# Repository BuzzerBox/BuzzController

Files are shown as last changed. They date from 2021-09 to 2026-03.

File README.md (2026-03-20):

# BuzzController

Firmware and hardware designs for the BuzzerBox — a 10-button quiz buzzer controller. A Raspberry Pi CM4 acts as the host, communicating with an ATmega328P co-processor over serial. The ATmega handles button detection, locks the active buzzer, and drives a 7-segment display.

---

## Features

- **10 buzzers** with individual LED feedback, interrupt-driven detection
- **7-segment display** showing the active buzzer number and RPi connection status
- **Serial communication** with a Raspberry Pi at 115200 baud, including heartbeat monitoring
- **Soft release** — RPi can remotely unlock the selected buzzer
- **Watchdog timer** for automatic recovery from firmware hangs
- **I2C I/O expanders** (MCP23017) to drive LEDs and display

---

## Repository Structure

```
BuzzController/
├── cad/
│   └── BuzzerBox/
│       ├── controller.brd/.sch    # Main ATmega328P controller board
│       ├── xlrpcb.brd/.sch        # XLR connector board (V3)
│       ├── devkeys.brd/.sch       # Development key PCB
│       ├── ttl_adapter.brd/.sch   # TTL adapter for devkit
│       └── eagle.epf              # EAGLE CAD project file
│   └── BuzzerBoxPanel.f3d         # Fusion 360 enclosure design
└── code/
    ├── platformio.ini             # Build configuration
    └── src/
        ├── BuzzerBox.cpp          # Main firmware logic
        ├── i2c_communication.*    # MCP23017 I/O expander driver
        ├── rpi_communication.*    # Serial protocol with Raspberry Pi
        ├── 7segment.*             # 7-segment display driver
        └── portConfig.hpp         # Pin/port and I2C address configuration
```

---

## Hardware

| Component | Details |
|---|---|
| Host | Raspberry Pi CM4 (mounted directly on PCB) |
| Microcontroller | ATmega328P |
| I/O Expanders | 2× MCP23017 (I2C addresses `0x20`, `0x21`) |
| Display | 7-segment LED (common cathode, via expander) |
| Buttons | 10 buzzers across MCU ports B, C, D + 1 release button |
| CM4 ↔ MCU | Serial UART (115200 baud) |
| Programming | STK500v2 via USB |

PCB designs are in [EAGLE](https://www.autodesk.com/products/eagle/overview) format. The enclosure panel is a [Fusion 360](https://www.autodesk.com/products/fusion-360/overview) file.

---

## Serial Protocol

Communication between the ATmega328P and the Raspberry Pi uses 3-byte UART messages at **115200 baud**:

```
[Command Byte] [Data Byte] [0xFF]
```

### Commands (RPi → Controller)

| Command | Value | Description |
|---|---|---|
| `EMPTY` | `0x00` | No operation |
| `SOFT_RELEASE` | `0x01` | Unlock the active buzzer |
| `SET_BUZZER` | `0x02` | Lock a specific buzzer (data = buzzer ID 0–9) |

### Events (Controller → RPi)

| Event | Byte | Description |
|---|---|---|
| Button pressed | `'0'`–`'9'` (ASCII) | Buzzer ID of the pressed button |
| Buzzer unlocked | `'q'` | Acknowledges an unlock |

A heartbeat is expected from the RPi every **6 seconds**. If no heartbeat is received within this window, the controller transitions to a disconnected state and reflects this on the display's decimal point.

---

## Building and Flashing

The firmware uses [PlatformIO](https://platformio.org/).

```bash
# Install PlatformIO CLI or use the VSCode extension

# Build
pio run

# Upload
pio run --target upload
```

Upload uses STK500v2 at 19200 baud over USB.

---

## Development

The `devkeys` PCB and `ttl_adapter` PCB are development accessories for testing the firmware without the full buzzer assembly.

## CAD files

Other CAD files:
cad/BuzzerBoxPanel.f3d

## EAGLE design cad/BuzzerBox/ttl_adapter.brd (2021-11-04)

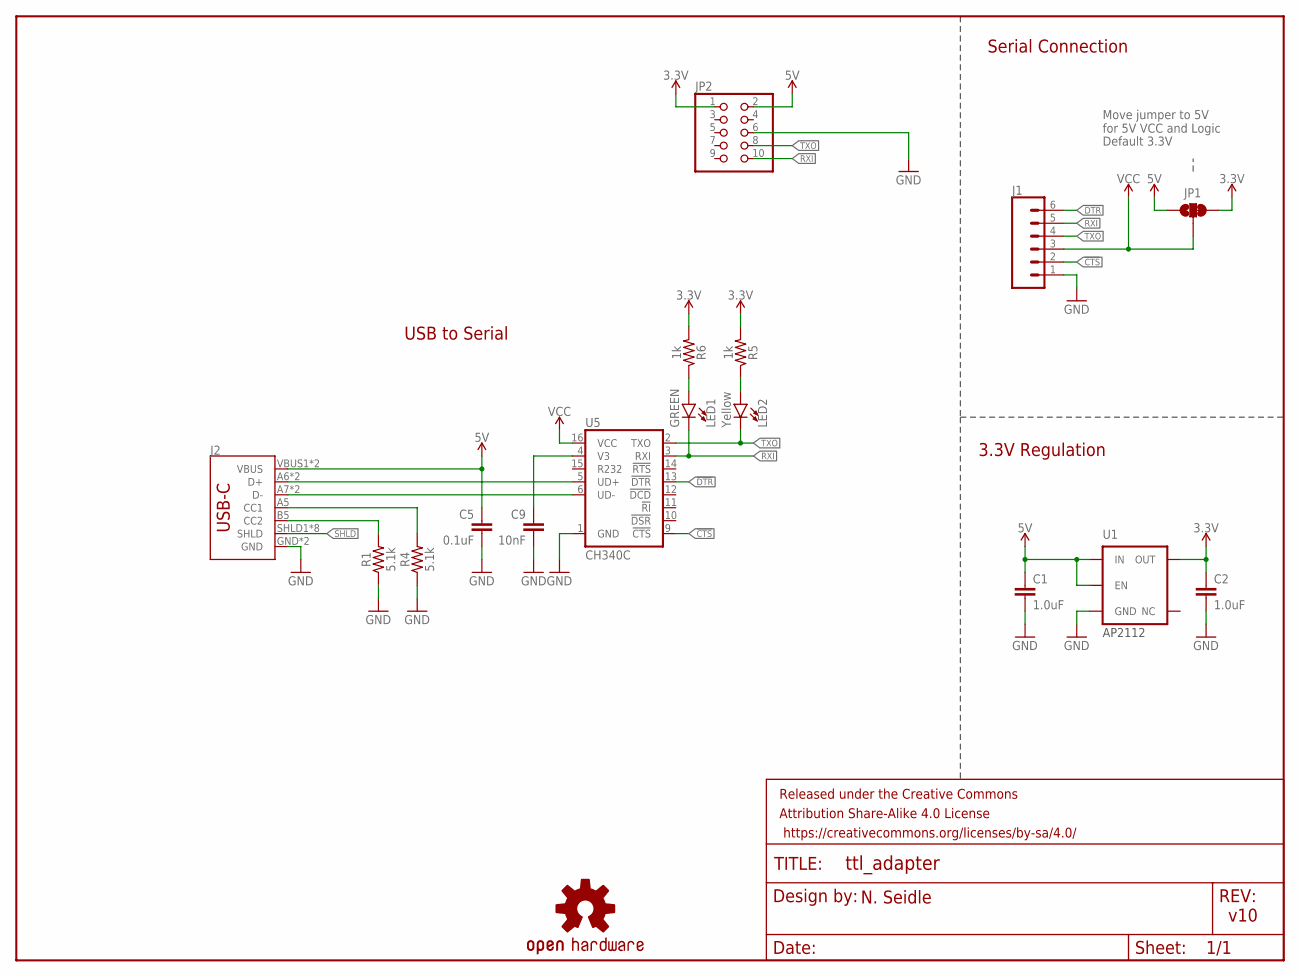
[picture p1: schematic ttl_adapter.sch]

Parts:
C1, C2: 1.0uF; 0603
C5: 0.1uF; 0603
C9: 10nF; 0603
FRAME1: FRAME-LETTER; CREATIVE_COMMONS
J1: CONN_06SMD-FEMALE-V2; 1X06-SMD-FEMALE
J2: USB_C16PIN; USB-C-16P
JP1: JUMPER-SMT_3_1-NC_TRACE_SILK; SMT-JUMPER_3_1-NC_TRACE_SILK
JP2: PINHD-2X5; 2X05
LED1: GREEN; LED-0603
LED2: Yellow; LED-0603
LOGO1: OSHW-LOGOS; OSHW-LOGO-S
R1, R4: 5.1k; 0603
R5, R6: 1k; 0603
U1: 3.3V; SOT23-5
U5: CH340C; SO016

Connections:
3.3V: C2.1, JP1.3, JP2.1, R5.2, R6.2, U1.5 (OUT)
5V: C1.1, C5.1, J2.VBUS1 (VBUS), J2.VBUS2 (VBUS), JP1.1, JP2.2, U1.1 (IN), U1.3 (EN)
!CTS: J1.2, U5.9 (!CTS)
!DTR: J1.6, U5.13 (!DTR)
CC1: J2.A5 (CC1), R4.2
CC2: J2.B5 (CC2), R1.2
D+: J2.A6 (D+), J2.B6 (D+), U5.5 (UD+)
D-: J2.A7 (D-), J2.B7 (D-), U5.6 (UD-)
GND: C1.2, C2.2, C5.2, C9.2, J1.1, J2.GND, J2.GND2 (GND), JP2.6, R1.1, R4.1, U1.2 (GND), U5.1 (GND)
unnamed: C9.1, U5.4 (V3)
unnamed: LED1.A, R6.1
unnamed: LED2.A, R5.1
RXI: J1.5, JP2.10, LED1.C, U5.3 (RXI)
SHLD: J2.SHLD1 (SHLD), J2.SHLD2 (SHLD), J2.SHLD3 (SHLD), J2.SHLD4 (SHLD), J2.SHLD5 (SHLD), J2.SHLD6 (SHLD), J2.SHLD7 (SHLD), J2.SHLD8 (SHLD)
TXO: J1.4, JP2.8, LED2.C, U5.2 (TXO)
VCC: J1.3, JP1.2, U5.16 (VCC)

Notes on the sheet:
Default 3.3V
v10
USB to Serial
3.3V Regulation
N. Seidle
Move jumper to 5V for 5V VCC and Logic
Serial Connection
AP2112

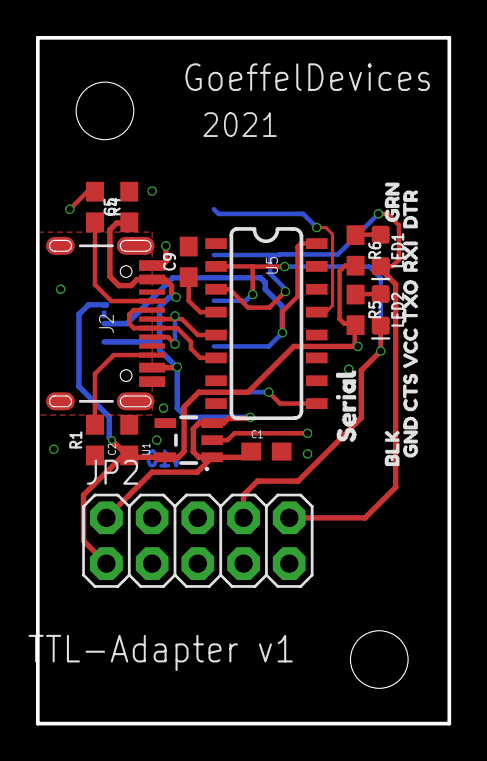
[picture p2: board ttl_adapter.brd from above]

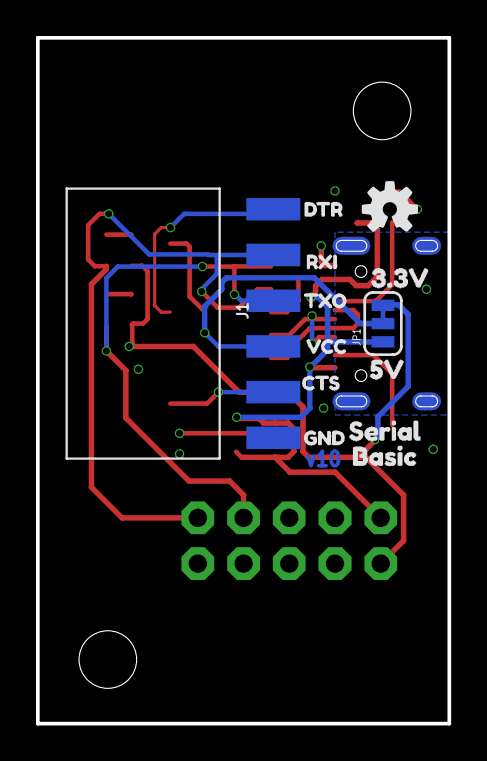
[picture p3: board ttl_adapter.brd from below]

Board: 2 copper layers, 22.9 x 38.1 mm, 39 parts (13 on the bottom side), 16 nets.

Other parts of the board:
U$1, U$14: CTS1
U$2: 3#3V8
U$3: 5V9
U$4, U$9: SERIAL0
U$5, U$12: TXO0
U$6, U$13: VCC2
U$8, U$18: DTR0
U$10, U$21: RXI1
U$11: BASIC1
U$15, U$19: GND5
U$16, U$22: M3-HOLE
U$17: BLK6
U$20: GRN7

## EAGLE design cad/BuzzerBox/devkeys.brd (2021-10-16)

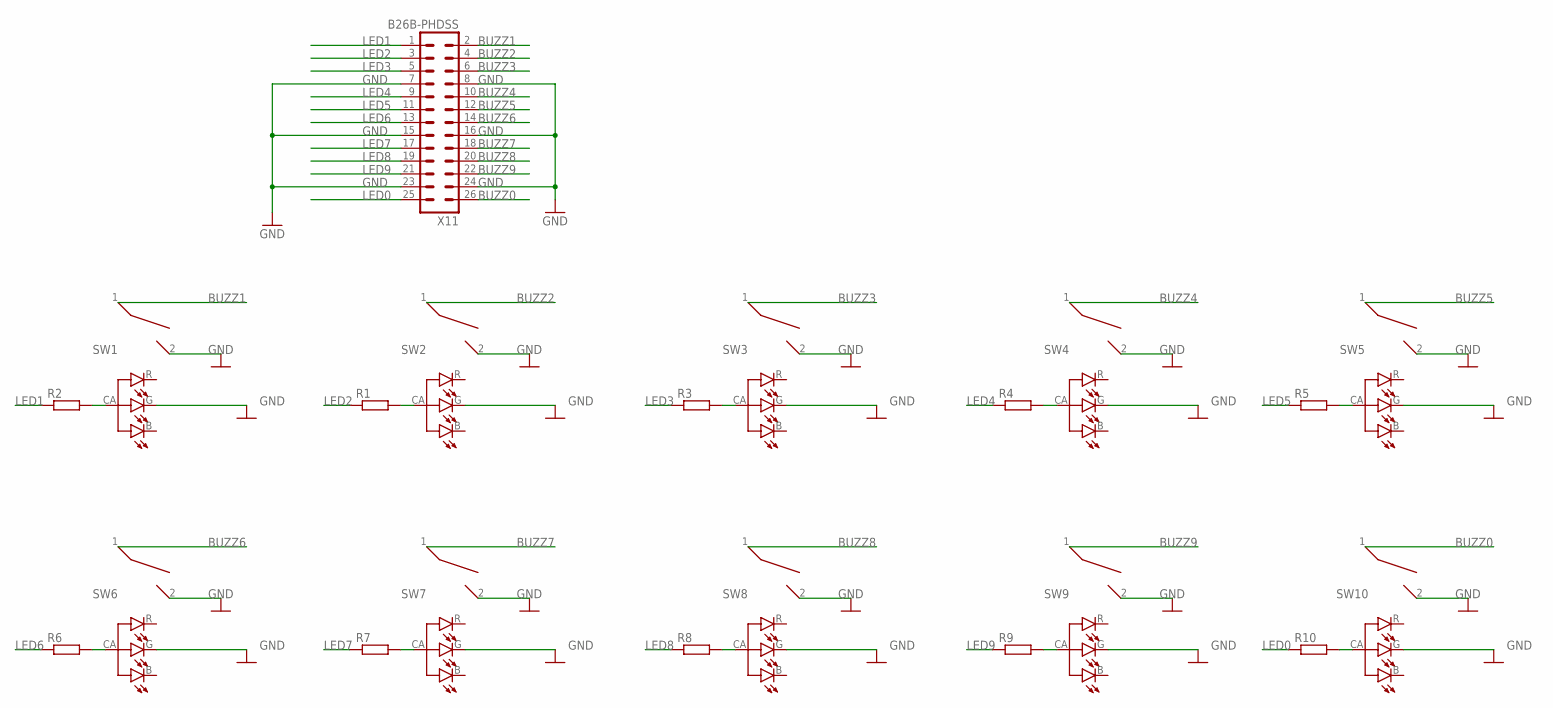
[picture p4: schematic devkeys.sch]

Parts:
R1, R2, R3, R4, R5, R6, R7, R8, R9, R10: R-EU_R0805; R0805
SW1, SW2, SW3, SW4, SW5, SW6, SW7, SW8, SW9, SW10: ZEALIOS; ZEALIOS-PCB_1U
X11: B26B-PHDSS

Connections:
BUZZ0: SW10.1, X11.26
BUZZ1: SW1.1, X11.2
BUZZ2: SW2.1, X11.4
BUZZ3: SW3.1, X11.6
BUZZ4: SW4.1, X11.10
BUZZ5: SW5.1, X11.12
BUZZ6: SW6.1, X11.14
BUZZ7: SW7.1, X11.18
BUZZ8: SW8.1, X11.20
BUZZ9: SW9.1, X11.22
GND: SW1.2, SW1.G (G-CAT), SW2.2, SW2.G (G-CAT), SW3.2, SW3.G (G-CAT), SW4.2, SW4.G (G-CAT), SW5.2, SW5.G (G-CAT), SW6.2, SW6.G (G-CAT), SW7.2, SW7.G (G-CAT), SW8.2, SW8.G (G-CAT), SW9.2, SW9.G (G-CAT), SW10.2, SW10.G (G-CAT), X11.7, X11.8, X11.15, X11.16, X11.23, X11.24
LED0: R10.1, X11.25
LED1: R2.1, X11.1
LED2: R1.1, X11.3
LED3: R3.1, X11.5
LED4: R4.1, X11.9
LED5: R5.1, X11.11
LED6: R6.1, X11.13
LED7: R7.1, X11.17
LED8: R8.1, X11.19
LED9: R9.1, X11.21
unnamed: R1.2, SW2.CA (COMMON-ANODE)
unnamed: R2.2, SW1.CA (COMMON-ANODE)
unnamed: R3.2, SW3.CA (COMMON-ANODE)
unnamed: R4.2, SW4.CA (COMMON-ANODE)
unnamed: R5.2, SW5.CA (COMMON-ANODE)
unnamed: R6.2, SW6.CA (COMMON-ANODE)
unnamed: R7.2, SW7.CA (COMMON-ANODE)
unnamed: R8.2, SW8.CA (COMMON-ANODE)
unnamed: R9.2, SW9.CA (COMMON-ANODE)
unnamed: R10.2, SW10.CA (COMMON-ANODE)

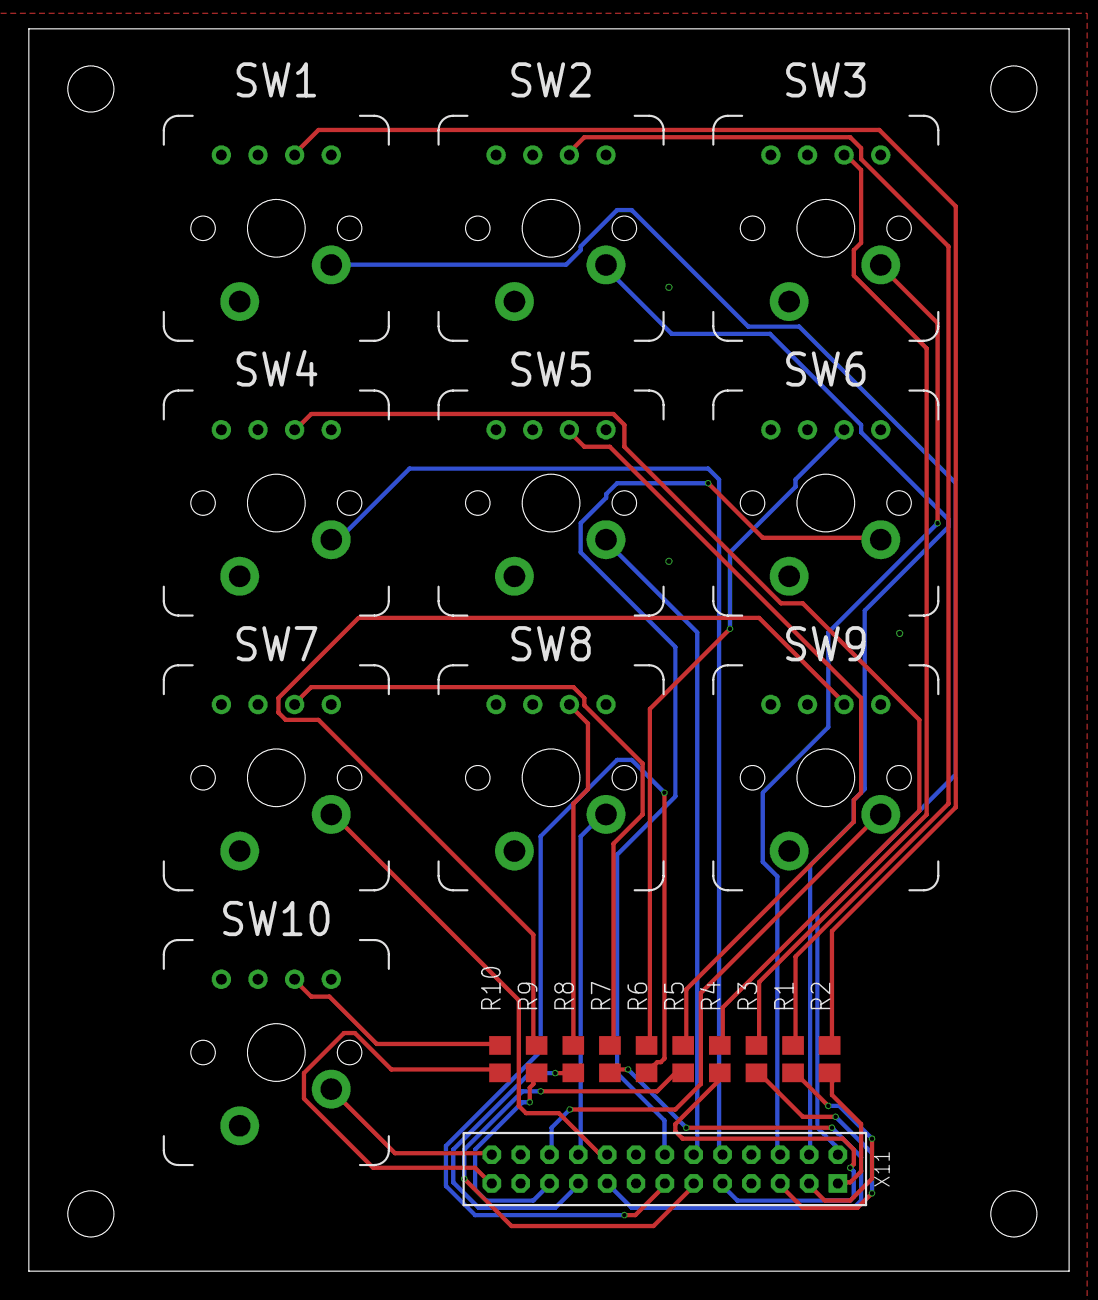
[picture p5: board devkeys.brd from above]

Board: 2 copper layers, 72.1 x 86.1 mm, 25 parts (0 on the bottom side), 31 nets.

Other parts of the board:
U$1, U$2, U$3, U$4: M3-HOLE

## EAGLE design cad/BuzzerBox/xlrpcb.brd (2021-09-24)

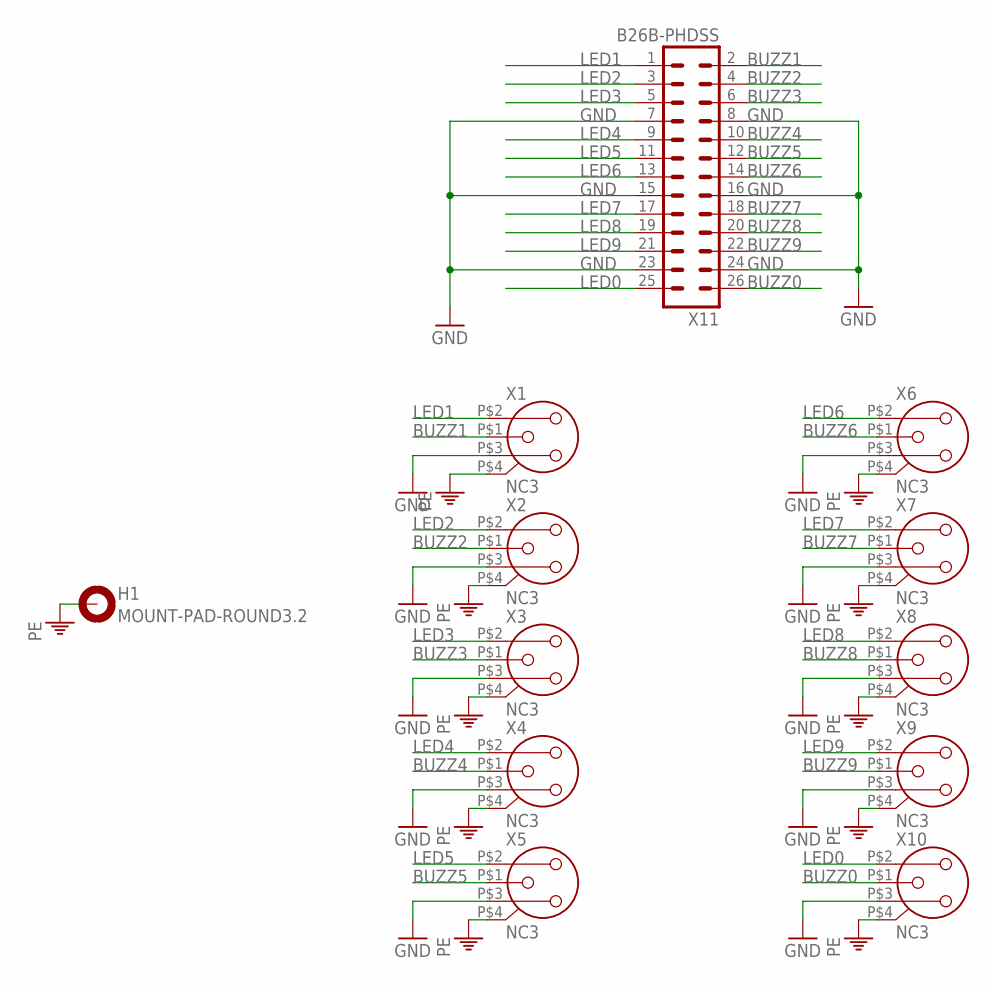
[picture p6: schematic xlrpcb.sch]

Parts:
H1: MOUNT-PAD-ROUND3.2; 3,2-PAD
X1, X2, X3, X4, X5, X6, X7, X8, X9, X10: NC3; NC3FD-X
X11: B26B-PHDSS

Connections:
BUZZ0: X10.P$1 (3), X11.26
BUZZ1: X1.P$1 (3), X11.2
BUZZ2: X2.P$1 (3), X11.4
BUZZ3: X3.P$1 (3), X11.6
BUZZ4: X4.P$1 (3), X11.10
BUZZ5: X5.P$1 (3), X11.12
BUZZ6: X6.P$1 (3), X11.14
BUZZ7: X7.P$1 (3), X11.18
BUZZ8: X8.P$1 (3), X11.20
BUZZ9: X9.P$1 (3), X11.22
GND: X1.P$3 (2), X2.P$3 (2), X3.P$3 (2), X4.P$3 (2), X5.P$3 (2), X6.P$3 (2), X7.P$3 (2), X8.P$3 (2), X9.P$3 (2), X10.P$3 (2), X11.7, X11.8, X11.15, X11.16, X11.23, X11.24
LED0: X10.P$2 (1), X11.25
LED1: X1.P$2 (1), X11.1
LED2: X2.P$2 (1), X11.3
LED3: X3.P$2 (1), X11.5
LED4: X4.P$2 (1), X11.9
LED5: X5.P$2 (1), X11.11
LED6: X6.P$2 (1), X11.13
LED7: X7.P$2 (1), X11.17
LED8: X8.P$2 (1), X11.19
LED9: X9.P$2 (1), X11.21
PE: H1.B3,2, X1.P$4 (G), X2.P$4 (G), X3.P$4 (G), X4.P$4 (G), X5.P$4 (G), X6.P$4 (G), X7.P$4 (G), X8.P$4 (G), X9.P$4 (G), X10.P$4 (G)

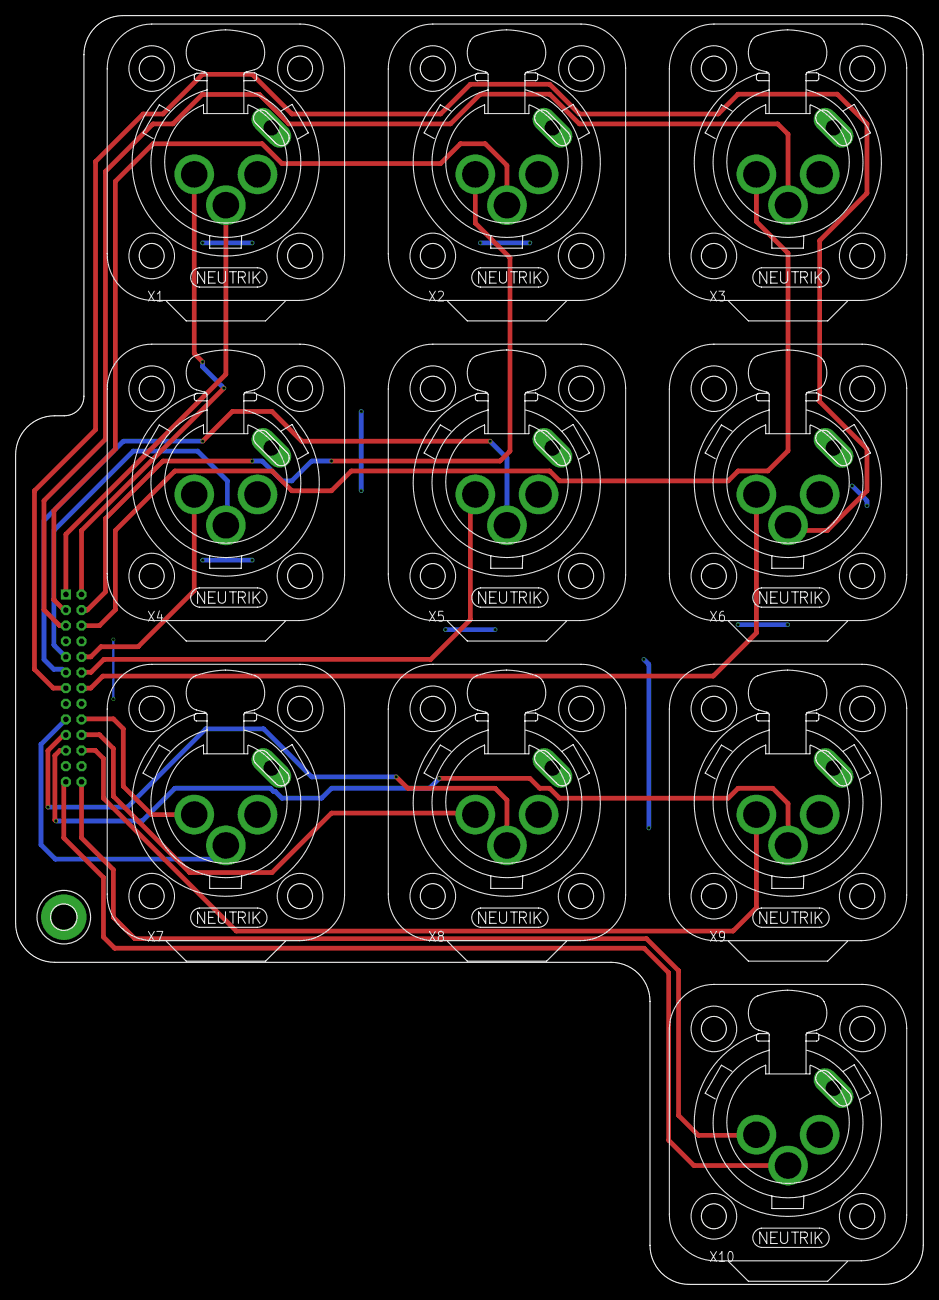
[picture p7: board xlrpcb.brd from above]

Board: 2 copper layers, 116.2 x 162.5 mm, 12 parts (1 on the bottom side), 22 nets.

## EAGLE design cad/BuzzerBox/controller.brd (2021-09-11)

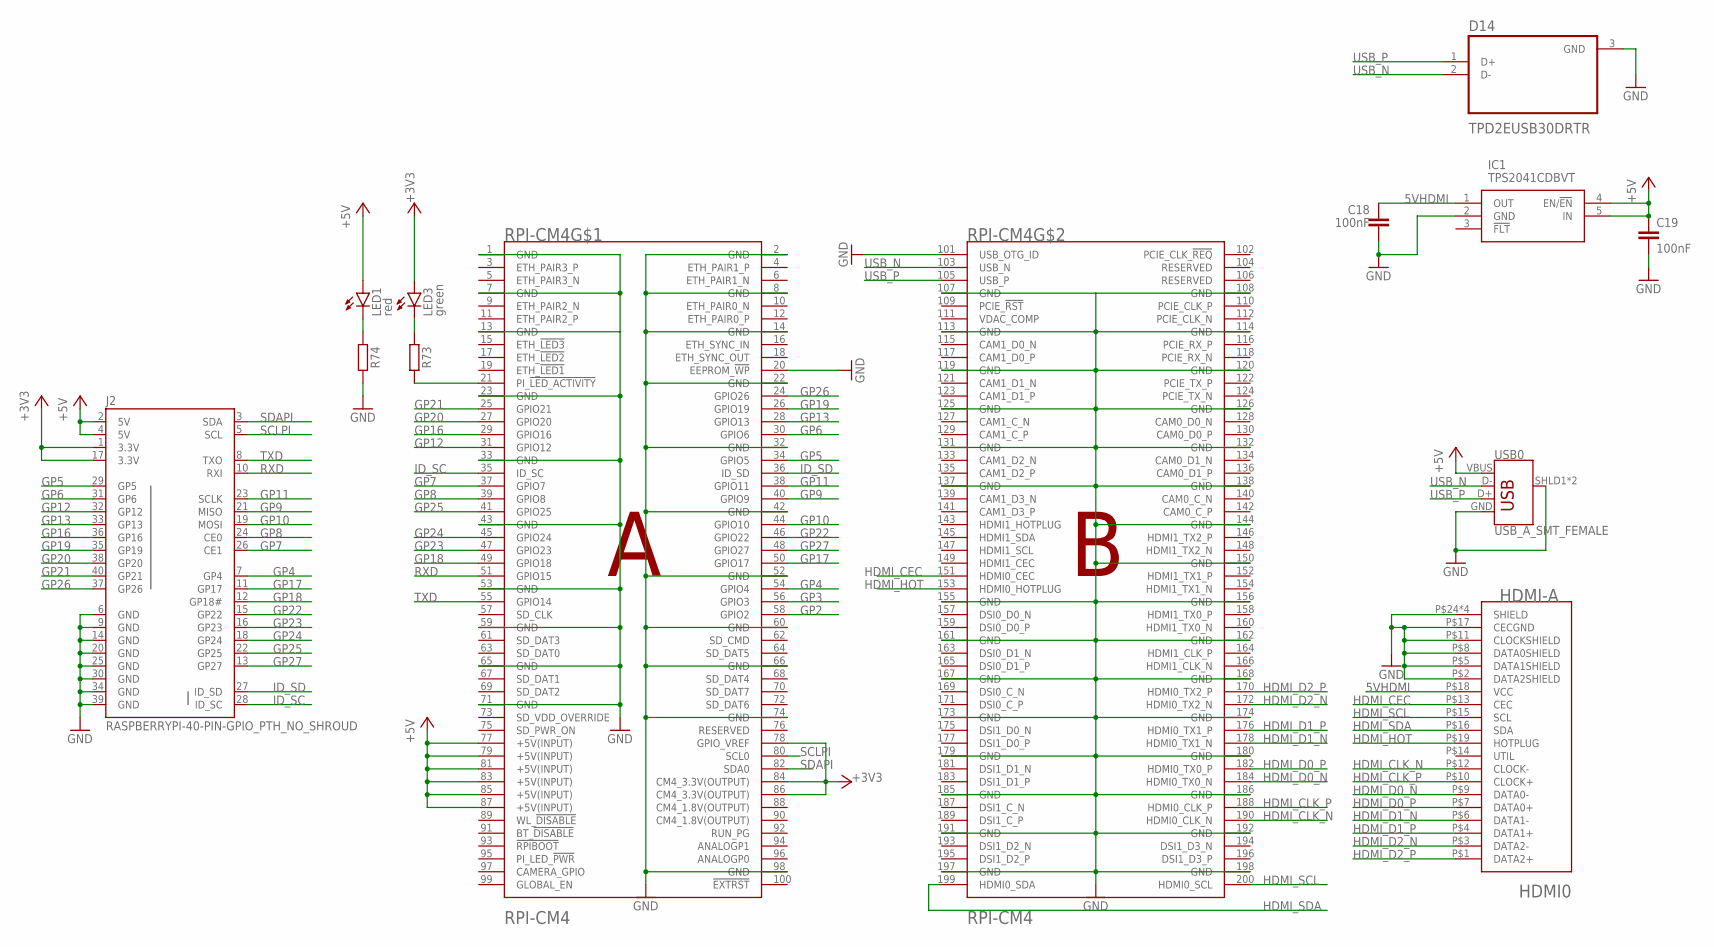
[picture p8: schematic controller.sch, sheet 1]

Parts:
C18, C19: 100nF; C0805
D14: TPD2EUSB30DRTR; SOTFL35P100X50-3N
HDMI0: HDMI-A; HDMI_A
IC1: TPS2041CDBVT; SOT95P280X145-5N
J2: RASPBERRYPI-40-PIN-GPIO_PTH_NO_SHROUD; 2X20
LED1: red; CHIP-LED0805
LED3: green; CHIP-LED0805
R73, R74: 1k; R0805
RPI-CM4: RPI-CM4
USB0: USB_A_SMT_FEMALE; USB-A-S-SILK-FEMALE

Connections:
5VHDMI: C18.1, HDMI0.P$18 (VCC), IC1.1 (OUT)
+3V3: J2.1 (3.3V), J2.17 (3.3V), LED3.A, RPI-CM4.78 (GPIO_VREF), RPI-CM4.84 (CM4_3.3V(OUTPUT)), RPI-CM4.86 (CM4_3.3V(OUTPUT)); also elsewhere on the board
+5V: C19.1, IC1.4 (EN/!EN), IC1.5 (IN), J2.2 (5V), J2.4 (5V), LED1.A, RPI-CM4.77 (+5V(INPUT)), RPI-CM4.79 (+5V(INPUT)), RPI-CM4.81 (+5V(INPUT)), RPI-CM4.83 (+5V(INPUT)), RPI-CM4.85 (+5V(INPUT)), RPI-CM4.87 (+5V(INPUT)), USB0.VBUS; also elsewhere on the board
GND: C18.2, C19.2, D14.3 (GND), HDMI0.P$2 (DATA2SHIELD), HDMI0.P$5 (DATA1SHIELD), HDMI0.P$8 (DATA0SHIELD), HDMI0.P$11 (CLOCKSHIELD), HDMI0.P$17 (CECGND), HDMI0.P$24 (SHIELD), HDMI0.P$25 (SHIELD), HDMI0.P$26 (SHIELD), HDMI0.P$27 (SHIELD), IC1.2 (GND), J2.6 (GND), J2.9 (GND), J2.14 (GND), J2.20 (GND), J2.25 (GND), J2.30 (GND), J2.34 (GND), J2.39 (GND), R74.2, RPI-CM4.1 (GND), RPI-CM4.2 (GND), RPI-CM4.7 (GND), RPI-CM4.8 (GND), RPI-CM4.13 (GND), RPI-CM4.14 (GND), RPI-CM4.20 (EEPROM_!WP), RPI-CM4.22 (GND), RPI-CM4.23 (GND), RPI-CM4.32 (GND), RPI-CM4.33 (GND), RPI-CM4.42 (GND), RPI-CM4.43 (GND), RPI-CM4.52 (GND), RPI-CM4.53 (GND), RPI-CM4.59 (GND), RPI-CM4.60 (GND), RPI-CM4.65 (GND), RPI-CM4.66 (GND), RPI-CM4.71 (GND), RPI-CM4.74 (GND), RPI-CM4.98 (GND), RPI-CM4.101 (USB_OTG_ID), RPI-CM4.107 (GND), RPI-CM4.108 (GND), RPI-CM4.113 (GND), RPI-CM4.114 (GND), RPI-CM4.119 (GND), RPI-CM4.120 (GND), RPI-CM4.125 (GND), RPI-CM4.126 (GND), RPI-CM4.131 (GND), RPI-CM4.132 (GND), RPI-CM4.137 (GND), RPI-CM4.138 (GND), RPI-CM4.144 (GND), RPI-CM4.150 (GND), RPI-CM4.155 (GND), RPI-CM4.156 (GND), RPI-CM4.161 (GND), RPI-CM4.162 (GND), RPI-CM4.167 (GND), RPI-CM4.168 (GND), RPI-CM4.173 (GND), RPI-CM4.174 (GND), RPI-CM4.179 (GND), RPI-CM4.180 (GND), RPI-CM4.185 (GND), RPI-CM4.186 (GND), RPI-CM4.191 (GND), RPI-CM4.192 (GND), RPI-CM4.197 (GND), RPI-CM4.198 (GND), USB0.GND, USB0.SHLD1 (SHIELD), USB0.SHLD2 (SHIELD); also elsewhere on the board
GP2: RPI-CM4.58 (GPIO2)
GP3: RPI-CM4.56 (GPIO3)
GP4: J2.7 (GP4), RPI-CM4.54 (GPIO4)
GP5: J2.29 (GP5), RPI-CM4.34 (GPIO5)
GP6: J2.31 (GP6), RPI-CM4.30 (GPIO6)
GP7: J2.26 (CE1), RPI-CM4.37 (GPIO7)
GP8: J2.24 (CE0), RPI-CM4.39 (GPIO8)
GP9: J2.21 (MISO), RPI-CM4.40 (GPIO9)
GP10: J2.19 (MOSI), RPI-CM4.44 (GPIO10)
GP11: J2.23 (SCLK), RPI-CM4.38 (GPIO11)
GP12: J2.32 (GP12), RPI-CM4.31 (GPIO12)
GP13: J2.33 (GP13), RPI-CM4.28 (GPIO13)
GP16: J2.36 (GP16), RPI-CM4.29 (GPIO16)
GP17: J2.11 (GP17), RPI-CM4.50 (GPIO17)
GP18: J2.12 (GP18#), RPI-CM4.49 (GPIO18)
GP19: J2.35 (GP19), RPI-CM4.26 (GPIO19)
GP20: J2.38 (GP20), RPI-CM4.27 (GPIO20)
GP21: J2.40 (GP21), RPI-CM4.25 (GPIO21)
GP22: J2.15 (GP22), RPI-CM4.46 (GPIO22)
GP23: J2.16 (GP23), RPI-CM4.47 (GPIO23); also elsewhere on the board
GP24: J2.18 (GP24), RPI-CM4.45 (GPIO24)
GP25: J2.22 (GP25), RPI-CM4.41 (GPIO25)
GP26: J2.37 (GP26), RPI-CM4.24 (GPIO26)
GP27: J2.13 (GP27), RPI-CM4.48 (GPIO27)
HDMI_CEC: HDMI0.P$13 (CEC), RPI-CM4.151 (HDMI0_CEC)
HDMI_CLK_N: HDMI0.P$12 (CLOCK-), RPI-CM4.190 (HDMI0_CLK_N)
HDMI_CLK_P: HDMI0.P$10 (CLOCK+), RPI-CM4.188 (HDMI0_CLK_P)
HDMI_D0_N: HDMI0.P$9 (DATA0-), RPI-CM4.184 (HDMI0_TX0_N)
HDMI_D0_P: HDMI0.P$7 (DATA0+), RPI-CM4.182 (HDMI0_TX0_P)
HDMI_D1_N: HDMI0.P$6 (DATA1-), RPI-CM4.178 (HDMI0_TX1_N)
HDMI_D1_P: HDMI0.P$4 (DATA1+), RPI-CM4.176 (HDMI0_TX1_P)
HDMI_D2_N: HDMI0.P$3 (DATA2-), RPI-CM4.172 (HDMI0_TX2_N)
HDMI_D2_P: HDMI0.P$1 (DATA2+), RPI-CM4.170 (HDMI0_TX2_P)
HDMI_HOT: HDMI0.P$19 (HOTPLUG), RPI-CM4.153 (HDMI0_HOTPLUG)
HDMI_SCL: HDMI0.P$15 (SCL), RPI-CM4.200 (HDMI0_SCL)
HDMI_SDA: HDMI0.P$16 (SDA), RPI-CM4.199 (HDMI0_SDA)
ID_SC: J2.28 (ID_SC), RPI-CM4.35 (ID_SC)
ID_SD: J2.27 (ID_SD), RPI-CM4.36 (ID_SD)
unnamed: R73.2, RPI-CM4.21 (PI_!LED_ACTIVITY)
unnamed: LED3.C, R73.1
unnamed: LED1.C, R74.1
RXD: J2.10 (RXI), RPI-CM4.51 (GPIO15); also elsewhere on the board
SCLPI: J2.5 (SCL), RPI-CM4.80 (SCL0)
SDAPI: J2.3 (SDA), RPI-CM4.82 (SDA0)
TXD: J2.8 (TXO), RPI-CM4.55 (GPIO14); also elsewhere on the board
USB_N: D14.2 (D-), RPI-CM4.103 (USB_N), USB0.D-
USB_P: D14.1 (D+), RPI-CM4.105 (USB_P), USB0.D+

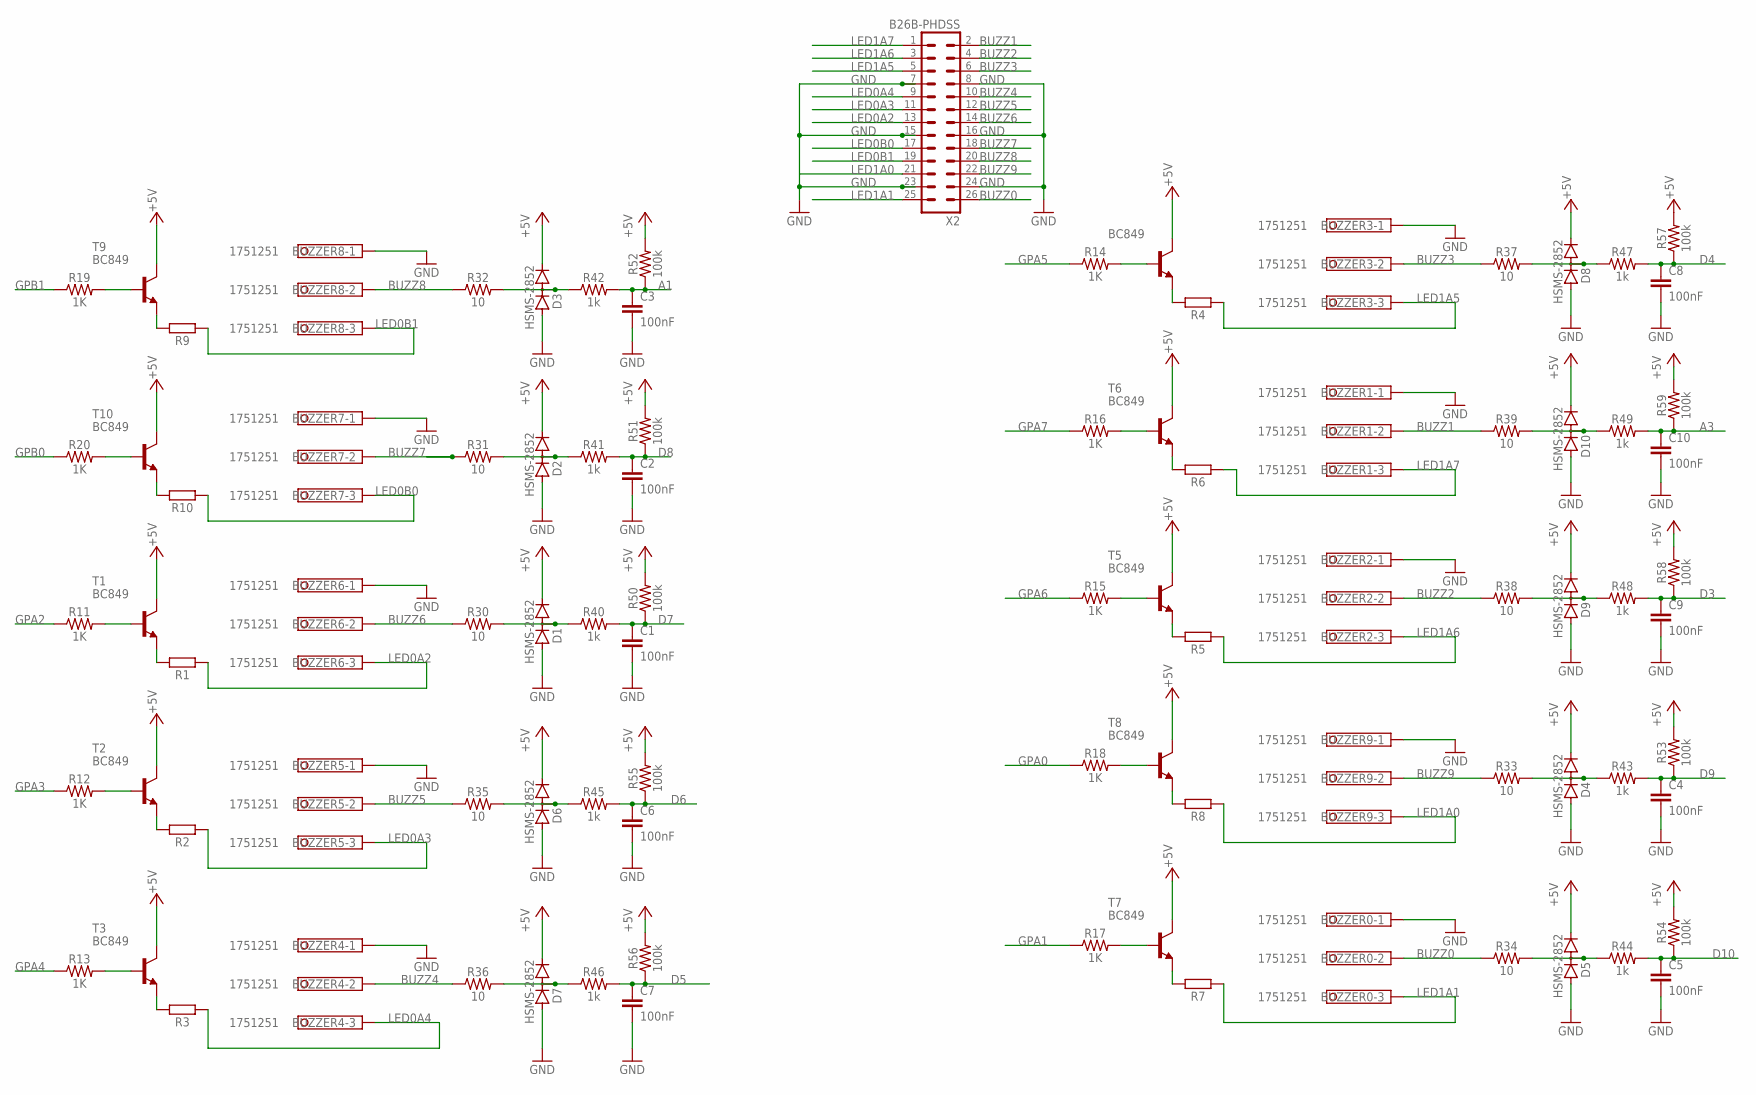
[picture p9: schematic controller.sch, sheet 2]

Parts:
BUZZER0, BUZZER1, BUZZER2, BUZZER3, BUZZER4, BUZZER5, BUZZER6, BUZZER7, BUZZER8, BUZZER9: 1751251
C1, C2, C3, C4, C5, C6, C7, C8, C9, C10: 100nF; C0805
D1, D2, D3, D4, D5, D6, D7, D8, D9, D10: HSMS-2852; SOT23
R1, R2, R3, R4, R5, R6, R7, R8, R9, R10: 50; R2512
R11, R12, R13, R14, R15, R16, R17, R18, R19, R20: 1K; 0805
R30, R31, R32, R33, R34, R35, R36, R37, R38, R39: 10; 0805
R40, R41, R42, R43, R44, R45, R46, R47, R48, R49: 1k; 0805
R50, R51, R52, R53, R54, R55, R56, R57, R58, R59: 100k; 0805
T1, T2, T3, T4, T5, T6, T7, T8, T9, T10: BC849; SOT23
X2: B26B-PHDSS

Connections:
+5V: D1.2 (C), D2.2 (C), D3.2 (C), D4.2 (C), D5.2 (C), D6.2 (C), D7.2 (C), D8.2 (C), D9.2 (C), D10.2 (C), R50.2, R51.2, R52.2, R53.2, R54.2, R55.2, R56.2, R57.2, R58.2, R59.2, T1.3 (C), T2.3 (C), T3.3 (C), T4.3 (C), T5.3 (C), T6.3 (C), T7.3 (C), T8.3 (C), T9.3 (C), T10.3 (C); also elsewhere on the board
A1: C3.1, R42.2, R52.1; also elsewhere on the board
A3: C10.1, R49.2, R59.1; also elsewhere on the board
BUZZ0: BUZZER0.2, R34.1, X2.26
BUZZ1: BUZZER1.2, R39.1, X2.2
BUZZ2: BUZZER2.2, R38.1, X2.4
BUZZ3: BUZZER3.2, R37.1, X2.6
BUZZ4: BUZZER4.2, R36.1, X2.10
BUZZ5: BUZZER5.2, R35.1, X2.12
BUZZ6: BUZZER6.2, R30.1, X2.14
BUZZ7: BUZZER7.2, R31.1, X2.18
BUZZ8: BUZZER8.2, R32.1, X2.20
BUZZ9: BUZZER9.2, R33.1, X2.22
D3: C9.1, R48.2, R58.1; also elsewhere on the board
D4: C8.1, R47.2, R57.1; also elsewhere on the board
D5: C7.1, R46.2, R56.1; also elsewhere on the board
D6: C6.1, R45.2, R55.1; also elsewhere on the board
D7: C1.1, R40.2, R50.1; also elsewhere on the board
D8: C2.1, R41.2, R51.1; also elsewhere on the board
D9: C4.1, R43.2, R53.1; also elsewhere on the board
D10: C5.1, R44.2, R54.1; also elsewhere on the board
GND: BUZZER0.1, BUZZER1.1, BUZZER2.1, BUZZER3.1, BUZZER4.1, BUZZER5.1, BUZZER6.1, BUZZER7.1, BUZZER8.1, BUZZER9.1, C1.2, C2.2, C3.2, C4.2, C5.2, C6.2, C7.2, C8.2, C9.2, C10.2, D1.1 (A), D2.1 (A), D3.1 (A), D4.1 (A), D5.1 (A), D6.1 (A), D7.1 (A), D8.1 (A), D9.1 (A), D10.1 (A), X2.7, X2.8, X2.15, X2.16, X2.23, X2.24; also elsewhere on the board
GPA0: R18.1; also elsewhere on the board
GPA1: R17.1; also elsewhere on the board
GPA2: R11.1; also elsewhere on the board
GPA3: R12.1; also elsewhere on the board
GPA4: R13.1; also elsewhere on the board
GPA5: R14.1; also elsewhere on the board
GPA6: R15.1; also elsewhere on the board
GPA7: R16.1; also elsewhere on the board
GPB0: R20.1; also elsewhere on the board
GPB1: R19.1; also elsewhere on the board
LED0A2: BUZZER6.3, R1.1, X2.13
LED0A3: BUZZER5.3, R2.1, X2.11
LED0A4: BUZZER4.3, R3.1, X2.9
LED0B0: BUZZER7.3, R10.1, X2.17
LED0B1: BUZZER8.3, R9.1, X2.19
LED1A0: BUZZER9.3, R8.1, X2.21
LED1A1: BUZZER0.3, R7.1, X2.25
LED1A5: BUZZER3.3, R4.1, X2.5
LED1A6: BUZZER2.3, R5.1, X2.3
LED1A7: BUZZER1.3, R6.1, X2.1
unnamed: R14.2, T4.1 (B)
unnamed: R4.2, T4.2 (E)
unnamed: D3.3 (AC), R32.2, R42.1
unnamed: R16.2, T6.1 (B)
unnamed: D2.3 (AC), R31.2, R41.1
unnamed: D8.3 (AC), R37.2, R47.1
unnamed: R6.2, T6.2 (E)
unnamed: D1.3 (AC), R30.2, R40.1
unnamed: R15.2, T5.1 (B)
unnamed: R5.2, T5.2 (E)
unnamed: D6.3 (AC), R35.2, R45.1
unnamed: D10.3 (AC), R39.2, R49.1
unnamed: R18.2, T8.1 (B)
unnamed: D7.3 (AC), R36.2, R46.1
unnamed: R8.2, T8.2 (E)
unnamed: D9.3 (AC), R38.2, R48.1
unnamed: R17.2, T7.1 (B)
unnamed: D4.3 (AC), R33.2, R43.1
unnamed: R7.2, T7.2 (E)
unnamed: R19.2, T9.1 (B)
unnamed: R9.2, T9.2 (E)
unnamed: R20.2, T10.1 (B)
unnamed: R10.2, T10.2 (E)
unnamed: R11.2, T1.1 (B)
unnamed: R1.2, T1.2 (E)
unnamed: R12.2, T2.1 (B)
unnamed: R2.2, T2.2 (E)
unnamed: R13.2, T3.1 (B)
unnamed: R3.2, T3.2 (E)
unnamed: D5.3 (AC), R34.2, R44.1

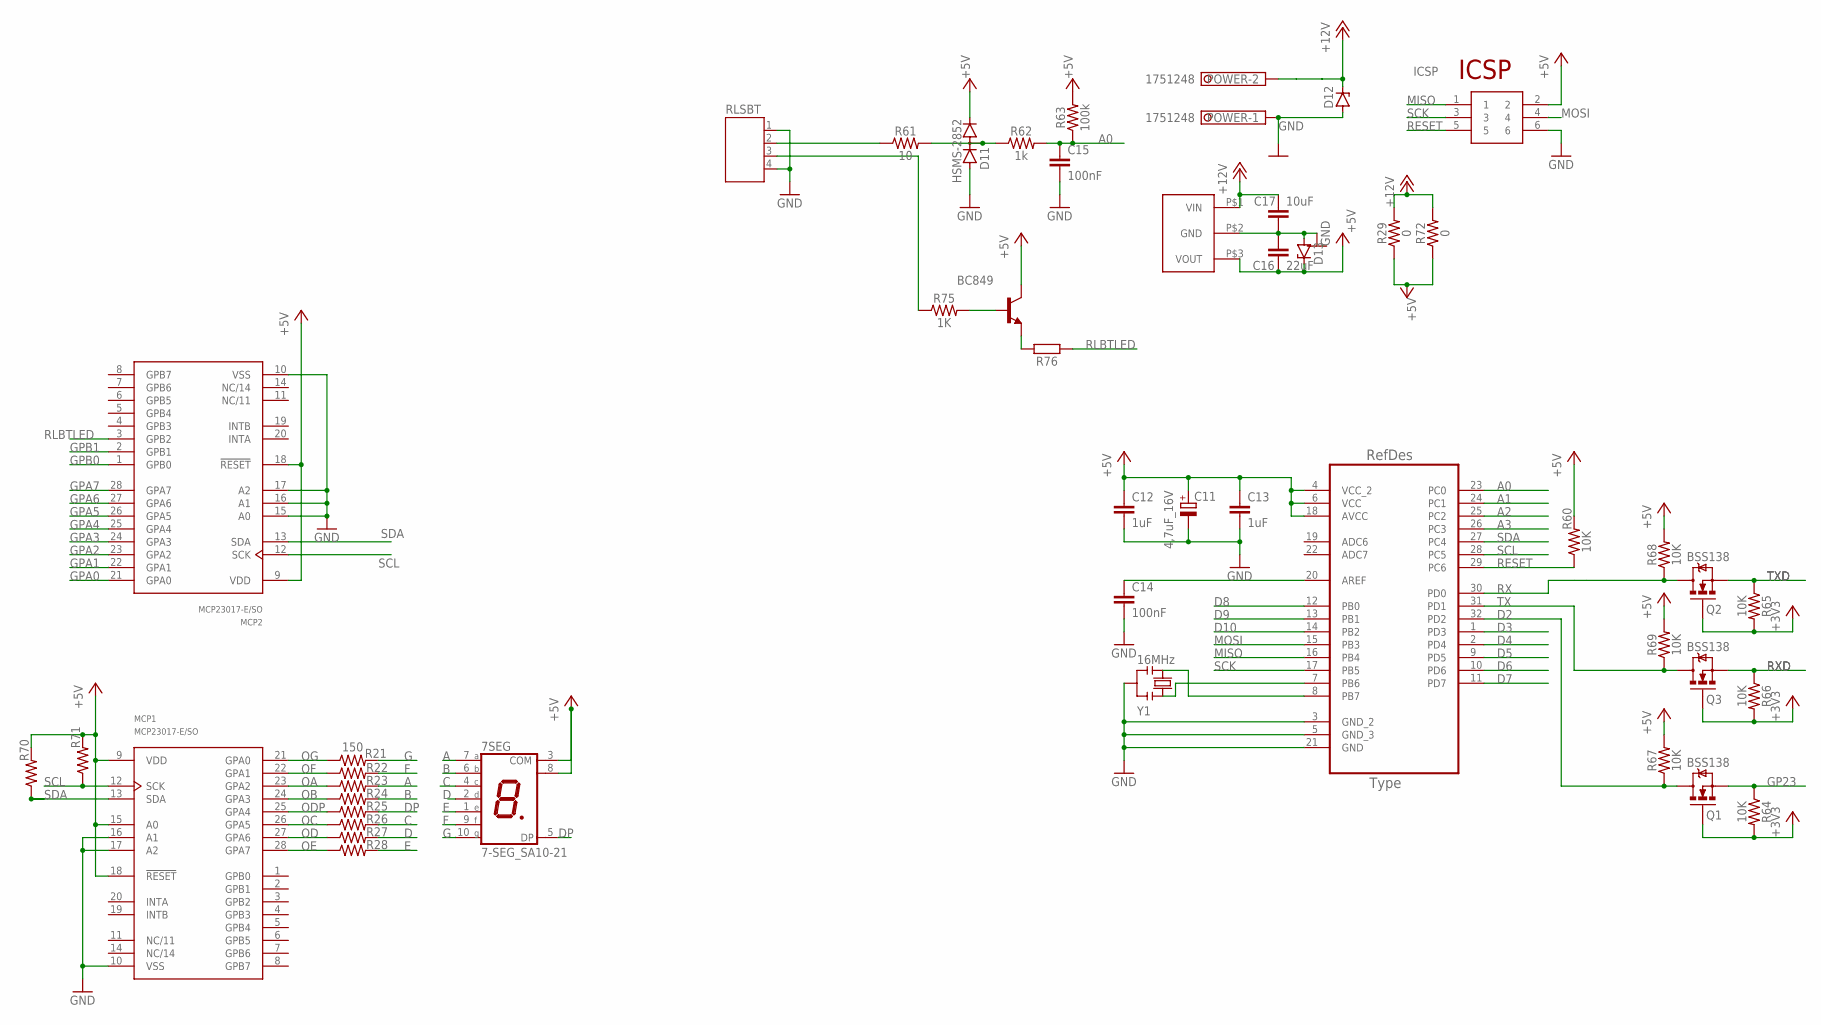
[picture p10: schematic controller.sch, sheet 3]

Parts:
7SEG: 7-SEG_SA10-21; SA10-21
C11: 4,7uF_16V; TAN-A
C12, C13: 1uF; C0603-ROUND
C14: 100nF; C0603-ROUND
C15: 100nF; C0805
C16: 22uF; C0805
C17: 10uF; C0805
D11: HSMS-2852; SOT23
D12, D13: ZENER-DIODESMB; SMB
ICSP: 61200621621; SHDR6W64P254_2X3_1528X910X910P
MCP1, MCP2: MCP23017-E/SO; SOIC28
POWER: 1751248
Q1, Q2, Q3: BSS138; SOT23-3
R21, R22, R23, R24, R25, R26, R27, R28: 150; 0805
R29, R72: 0; 0805
R60, R64, R65, R66, R67, R68, R69: 10K; 0805
R61: 10; 0805
R62: 1k; 0805
R63: 100k; 0805
R70, R71: 0805
R75: 1K; 0805
R76: 50; R2512
RLSBT: JST-PH4
T11: BC849; SOT23
U1: ATMEGA328P-AU; QFP80P900X900X120-32N
U$5: GAPTECCLC78; GAPTECLC78
Y1: 16MHz; RESONATOR

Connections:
+3V3: Q1.1 (G), Q2.1 (G), Q3.1 (G), R64.2, R65.2, R66.2; also elsewhere on the board
+5V: 7SEG.3 (COM), 7SEG.8 (COM), C11.1 (+), C12.1, C13.1, C16.2, D11.2 (C), D13.C, ICSP.2, MCP1.9 (VDD), MCP1.15 (A0), MCP1.18 (!RESET), MCP2.9 (VDD), MCP2.18 (!RESET), R29.1, R60.2, R63.2, R67.2, R68.2, R69.2, R70.2, R71.2, R72.1, T11.3 (C), U1.4 (VCC_2), U1.6 (VCC), U1.18 (AVCC), U$5.P$3 (VOUT); also elsewhere on the board
+12V: C17.1, D12.C, POWER.2, R29.2, R72.2, U$5.P$1 (VIN)
A: 7SEG.7 (A), R23.2
A0: C15.1, R62.2, R63.1, U1.23 (PC0)
A1: U1.24 (PC1); also elsewhere on the board
A2: U1.25 (PC2)
A3: U1.26 (PC3); also elsewhere on the board
B: 7SEG.6 (B), R24.2
C: 7SEG.4 (C), R26.2
D: 7SEG.2 (D), R27.2
D2: Q1.3 (D), R67.1, U1.32 (PD2)
D3: U1.1 (PD3); also elsewhere on the board
D4: U1.2 (PD4); also elsewhere on the board
D5: U1.9 (PD5); also elsewhere on the board
D6: U1.10 (PD6); also elsewhere on the board
D7: U1.11 (PD7); also elsewhere on the board
D8: U1.12 (PB0); also elsewhere on the board
D9: U1.13 (PB1); also elsewhere on the board
D10: U1.14 (PB2); also elsewhere on the board
DP: 7SEG.5 (DP), R25.2
E: 7SEG.1 (E), R28.2
F: 7SEG.9 (F), R22.2
G: 7SEG.10 (G), R21.2
GND: C11.2 (-), C12.2, C13.2, C14.2, C15.2, C16.1, C17.2, D11.1 (A), D12.A, D13.A, ICSP.6, MCP1.10 (VSS), MCP1.16 (A1), MCP1.17 (A2), MCP2.10 (VSS), MCP2.15 (A0), MCP2.16 (A1), MCP2.17 (A2), POWER.1, RLSBT.1, RLSBT.4, U1.3 (GND_2), U1.5 (GND_3), U1.21 (GND), U$5.P$2 (GND), Y1.2; also elsewhere on the board
GP23: Q1.2 (S), R64.1; also elsewhere on the board
GPA0: MCP2.21 (GPA0); also elsewhere on the board
GPA1: MCP2.22 (GPA1); also elsewhere on the board
GPA2: MCP2.23 (GPA2); also elsewhere on the board
GPA3: MCP2.24 (GPA3); also elsewhere on the board
GPA4: MCP2.25 (GPA4); also elsewhere on the board
GPA5: MCP2.26 (GPA5); also elsewhere on the board
GPA6: MCP2.27 (GPA6); also elsewhere on the board
GPA7: MCP2.28 (GPA7); also elsewhere on the board
GPB0: MCP2.1 (GPB0); also elsewhere on the board
GPB1: MCP2.2 (GPB1); also elsewhere on the board
MISO: ICSP.1, U1.16 (PB4)
MOSI: ICSP.4, U1.15 (PB3)
unnamed: U1.8 (PB7), Y1.3
unnamed: R75.2, T11.1 (B)
unnamed: R76.2, T11.2 (E)
unnamed: R75.1, RLSBT.3
unnamed: D11.3 (AC), R61.2, R62.1
unnamed: U1.7 (PB6), Y1.1
unnamed: C14.1, U1.20 (AREF)
OA: MCP1.23 (GPA2), R23.1
OB: MCP1.24 (GPA3), R24.1
OC: MCP1.26 (GPA5), R26.1
OD: MCP1.27 (GPA6), R27.1
ODP: MCP1.25 (GPA4), R25.1
OE: MCP1.28 (GPA7), R28.1
OF: MCP1.22 (GPA1), R22.1
OG: MCP1.21 (GPA0), R21.1
RESET: ICSP.5, R60.1, U1.29 (PC6)
RLBTLED: MCP2.3 (GPB2), R76.1
RLSBT: R61.1, RLSBT.2
RX: Q2.3 (D), R68.1, U1.30 (PD0)
RXD: Q3.2 (S), R66.1; also elsewhere on the board
SCK: ICSP.3, U1.17 (PB5)
SCL: MCP1.12 (SCK), MCP2.12 (SCK), R71.1, U1.28 (PC5)
SDA: MCP1.13 (SDA), MCP2.13 (SDA), R70.1, U1.27 (PC4)
TX: Q3.3 (D), R69.1, U1.31 (PD1)
TXD: Q2.2 (S), R65.1; also elsewhere on the board

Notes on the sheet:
ICSP

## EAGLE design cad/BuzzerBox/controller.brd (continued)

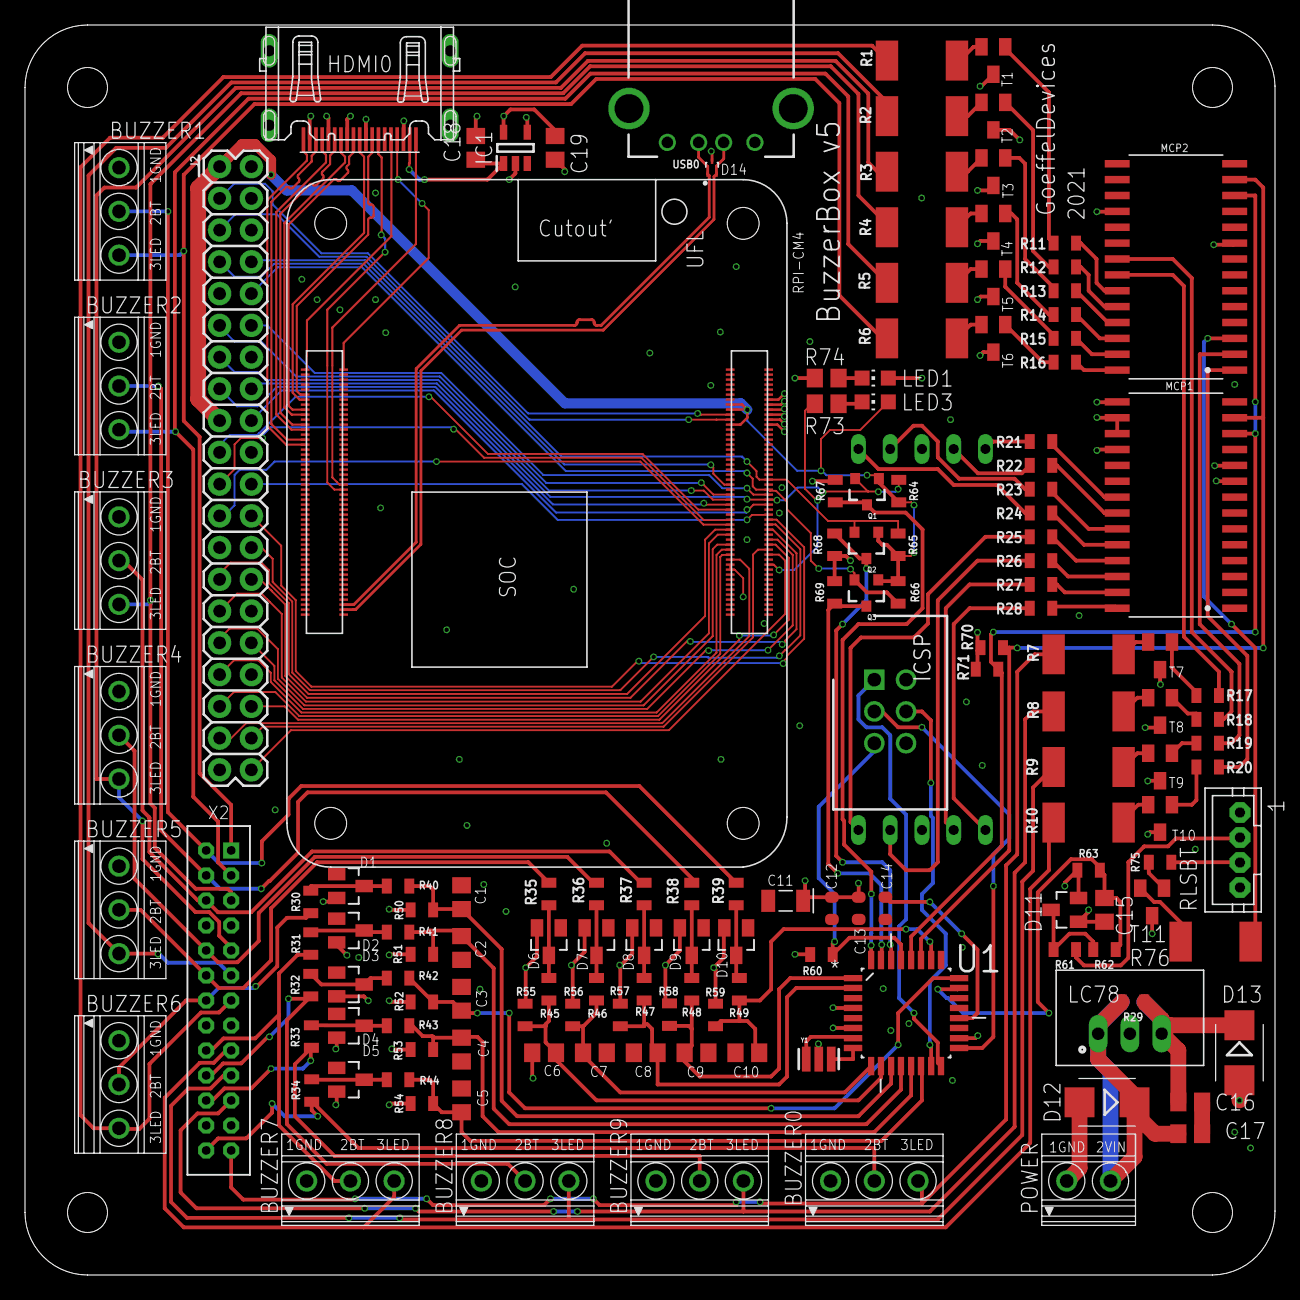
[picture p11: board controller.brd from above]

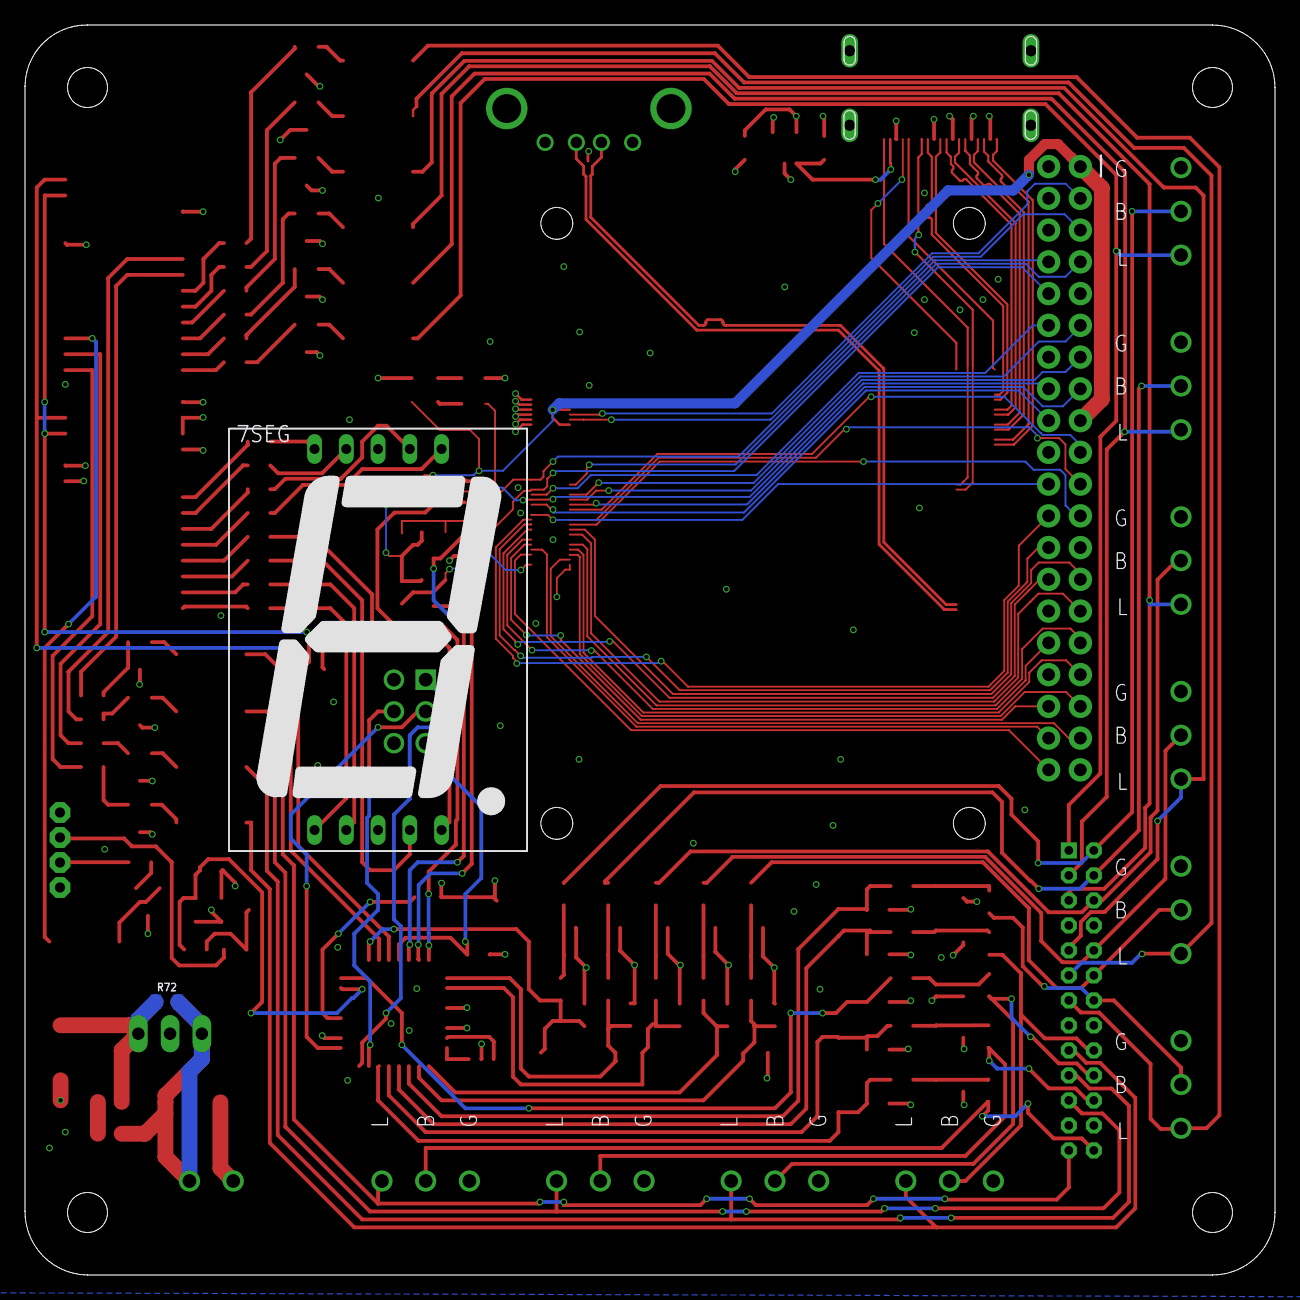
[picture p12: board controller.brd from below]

Board: 4 copper layers, 100.0 x 100.0 mm, 154 parts (2 on the bottom side), 155 nets.

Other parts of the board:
U$1, U$2, U$3, U$4: M3-HOLE

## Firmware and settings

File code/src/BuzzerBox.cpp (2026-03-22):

#include <Arduino.h>
#include "portConfig.hpp"
#include <avr/interrupt.h>
#include "7segment.hpp"
#include "i2c_communication.hpp"
#include "rpi_communication.hpp"

#include <avr/wdt.h>
volatile uint8_t port_interrupt_flag = 255;
volatile uint8_t pin_data = 0xFF;

RpiComm* rpiComm;
SevenSeg* sevenSeg;
I2CComm* i2cComm;

uint8_t b_select = B00000111;
uint8_t c_select = B00001010;
uint8_t d_select = B11111000;

boolean isLocked = false;
boolean rPiIsConnected = false;
uint8_t last_state[10] = {1};
uint8_t release_down_count = 0;
uint8_t release_was_high = 1;

uint8_t currentBuzzer = NO_BUZZER;

#define DEBOUNCE_MS 20
uint32_t debounce_start = 0;

// uint8_t lookup[] = {7, 0, 5, 1, 6, 4, 3, 2};
uint8_t getBitPosition(uint8_t b) {
  int i=0;
  while( !((b >> i) & 1) ) { 
    i++;  
  }
  return i;
  //return lookup[((b * 0x1D) >> 4) & 0x7];
}


void setup() {
  DDRB = B00000000;
  DDRC = B00000000;
  DDRD = B00000000;

  PORTB |= b_select;
  PORTC |= (c_select | 1); // Also configure Release
  PORTD |= d_select;

  cli();
  PCMSK0 |= b_select;
  PCMSK1 |= c_select;
  PCMSK2 |= d_select; // enable Interrupts on active pins for port d
  PCICR  |= 0b00000111; // enable Interrupt on all 3 ports
  sei();

  wdt_enable(WDTO_1S);
  
  rpiComm = new RpiComm();
  i2cComm = new I2CComm();
  sevenSeg = new SevenSeg(true, i2cComm);
  i2cComm->turnOffAll();
  i2cComm->turnOnSingle(buttons[4]);

}

ISR(PCINT0_vect)
{
  if (port_interrupt_flag == 255) {
    pin_data = PINB | ~b_select; 
    if (pin_data != 0xFF) {
      PCICR  &= ~0b00000111;
      port_interrupt_flag = 0;
    }
  }
}

ISR(PCINT1_vect)
{
  if (port_interrupt_flag == 255) {
    pin_data = PINC | ~c_select; 
    if (pin_data != 0xFF) {
      PCICR  &= ~0b00000111;
      port_interrupt_flag = 1;
    }
  }
}

ISR(PCINT2_vect)
{
  if (port_interrupt_flag == 255) {
    pin_data = PIND | ~d_select; 
    if (pin_data != 0xFF) {
      PCICR  &= ~0b00000111;
      port_interrupt_flag = 2;
    }
  }
}


void unlock() {
  isLocked = false;
  currentBuzzer = NO_BUZZER;
  sevenSeg->clearDisplay(!rPiIsConnected);
  i2cComm->turnOffAll();
  cli();
  PCICR  |= 0b00000111;
  sei();
  rpiComm->sendUnlock();
}

void lock(uint8_t buttonID) {
  isLocked = true;
  currentBuzzer = buttonID;
  sevenSeg->displayNumber(buttonID, !rPiIsConnected);
  i2cComm->turnOnSingle(buttons[buttonID]);
  rpiComm->sendButtonSelected(buttonID);
}

void checkCommand(PiCmd command) {
  if(command.command == EMPTY) return;
  rPiIsConnected = true;
  switch(command.command) {
    case SOFT_RELEASE:
      unlock();
      break;
    case SET_BUZZER:
      if(command.data <= 9) {
         lock(command.data);
      }
      break;
  }
  command.command = EMPTY;
}

void displayCurrentState() {
  if(currentBuzzer == NO_BUZZER) {
    sevenSeg->clearDisplay(!rPiIsConnected);
  } else {
    sevenSeg->displayNumber(currentBuzzer, !rPiIsConnected);
  }
}

void handleRpiConnectionState() {
  Pi_connection_state_t state = rpiComm->getConnectionState();
  if (state == JUST_CONNECTED) {
    rPiIsConnected = true;
    rpiComm->setConnectionState(CONNECTED);
    displayCurrentState();
  } else if (state == JUST_TIMED_OUT) {
    rPiIsConnected = false;
    rpiComm->setConnectionState(NO_CONNECTION);
    displayCurrentState();
  } else if (state == CONNECTED) {
    if (rpiComm->isTimedOut()) {
      rPiIsConnected = false;
      displayCurrentState();
      rpiComm->setConnectionState(NO_CONNECTION);
    }
  }
}

void loop() {
  if (rpiComm->checkData()) {
    checkCommand(rpiComm->getLastCmd());  
  }
  
  handleRpiConnectionState();
  uint8_t release_pressed = ~PINC & 1;
  if (release_pressed && release_was_high == 1) {
      if (isLocked == true && release_down_count > 10) {
        unlock();
        release_was_high = 0;
      }
      release_down_count++;
  } else {
    if (!release_pressed) release_was_high = 1;
    release_down_count = 0;
  }
    
  
  if(port_interrupt_flag != 255) {
    if (debounce_start == 0) {
      debounce_start = millis();
    } else if (millis() - debounce_start >= DEBOUNCE_MS) {
      if (!isLocked) {
        uint8_t confirmed_data;
        if (port_interrupt_flag == 0) {
          confirmed_data = PINB | ~b_select;
          if (confirmed_data != 0xFF)
            lock(buttonsB[getBitPosition(~confirmed_data)].number);
        } else if (port_interrupt_flag == 1) {
          confirmed_data = PINC | ~c_select;
          if (confirmed_data != 0xFF)
            lock(buttonsC[getBitPosition(~confirmed_data)].number);
        } else if (port_interrupt_flag == 2) {
          confirmed_data = PIND | ~d_select;
          if (confirmed_data != 0xFF)
            lock(buttonsD[getBitPosition(~confirmed_data)].number);
        }
      }
      port_interrupt_flag = 255;
      debounce_start = 0;
    }
  }
  wdt_reset();
}

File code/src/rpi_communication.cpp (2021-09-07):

#include "rpi_communication.hpp"
#define noop

RpiComm::RpiComm(int heartbeatTimeout) {
    this->heartbeatTimeout = heartbeatTimeout;
    Serial.begin(115200);
    connection_state = NO_CONNECTION;
}

void RpiComm::sendRawData(byte data) {
    Serial.write(data);
}

boolean RpiComm::checkData() {
  boolean hasCompleteMessage = false;
  if (Serial.available()) {
    byte readByte = Serial.read();
    if (readByte == 0xFF) {
      heartbeatDetected();
      if (cmd_fill == 2) {
        hasCompleteMessage = true;
      }
      cmd_fill = 0;
    } else {
      cmd_fill++;
      if (cmd_fill == 1) {
        current_command.command = readByte;
      } else if (cmd_fill == 2) {
        current_command.data = readByte;
      } else {
        cmd_fill = 0;
      }
    }
  }
  return hasCompleteMessage;
}

PiCmd RpiComm::getLastCmd() {
  return current_command;
}

void RpiComm::sendUnlock() {
   this->sendRawData('q');
}


void RpiComm::sendButtonSelected(byte buttonID) {
  this->sendRawData(buttonID + 48);
}

void RpiComm::heartbeatDetected() {
  switch(connection_state) {
    case NO_CONNECTION : 
      connection_state = JUST_CONNECTED;
      break;
    case JUST_TIMED_OUT :
      connection_state = JUST_CONNECTED;
      break;
    default: 
      noop;
  }
  lastConnection = millis();
}

Pi_connection_state_t RpiComm::getConnectionState() {
  return connection_state;
}

Pi_connection_state_t RpiComm::advanceConnectionState() {
  switch(connection_state) {
    case NO_CONNECTION : 
      connection_state = JUST_CONNECTED;
      break;
    case JUST_CONNECTED :
      connection_state = CONNECTED;
      break;
    case CONNECTED :
      connection_state = JUST_TIMED_OUT;
      break;
    case JUST_TIMED_OUT :
      connection_state = NO_CONNECTION;
      break;
  }
  return connection_state;
}

void RpiComm::setConnectionState(Pi_connection_state_t state) {
  connection_state = state;
}

bool RpiComm::isTimedOut() {
  if (connection_state == CONNECTED) {
    if (lastConnection + heartbeatTimeout < millis()) {
      connection_state = JUST_TIMED_OUT;
      return true;
    }
  }
  return false;
}

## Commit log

2021-05-09 Basic Button-Detection with Lock
2021-05-10 First draft PCB
    [controller.sch]
2021-05-11 PCB V1
    [controller.brd, controller.sch]
2021-05-20 Fix Boardlayout, Adapt code to Pro Micro
    [controller.brd]
2021-05-23 Fix obvious pcb issues from V1
    [controller.brd, controller.sch]
2021-05-24 Optimize Screw-Holes, postitions, pull back resist etc.
    [controller.brd]
2021-05-28 Add 7-Segment-Display to Layout
    [controller.brd, controller.sch]
2021-05-30 Add release button to board
    [controller.brd, controller.sch]
2021-05-30 Added Pullup Resistors to I2C-Bus
    [controller.brd, controller.sch]
2021-05-30 Clean up schematic
    [controller.brd, controller.sch]
2021-05-31 Cleanup schematic
    [controller.sch]
2021-05-31 Added transistors for more LED power
    [controller.brd, controller.sch]
2021-05-31 Placed all transistors
    [controller.brd]
2021-05-31 Reorganize Power-Supply, Add adjustment resistors to regulator
    [controller.brd, controller.sch]
2021-06-02 Final Board V2
    [controller.brd, controller.sch]
2021-06-03 Fix wrong silkscreen side for Buzzer connection ports
    [controller.brd, controller.sch]
2021-06-04 Update resistor values for BOM
    [controller.brd, controller.sch]
2021-06-05 Upgrade LED output resistors to bigger 2512 package to better handle larger currents
    [controller.brd, controller.sch]
2021-06-09 Reposition components to keep similar components close together, for easier compoent placment
    [controller.brd]
2021-06-10 Slight component rearangement
    [controller.brd]
2021-06-10 Place all compoenents in logical groups for easy placement
    [controller.brd]
2021-06-10 Move components closer together to create free space
    [controller.brd]
2021-06-10 Replaced Arduino with bare uC
    [controller.brd, controller.sch]
2021-06-10 Start adding the RPi CM4
    [controller.brd, controller.sch]
2021-06-13 Add USB port
    [controller.brd, controller.sch]
2021-06-18 Fix missig Reset pin voltage on I2c-expander
    [controller.brd, controller.sch]
2021-06-18 Consider basic button implementation
2021-06-20 Added Panel
    [BuzzerBoxPanel v23.f3d]
2021-06-21 Reorder Buzzers to match PCB-Silkscreen
2021-06-25 Add Side-Channel Signal line between uC and RPi
    [controller.brd, controller.sch]
2021-06-25 Added HDMI
    [controller.brd, controller.sch]
2021-06-25 Add pin header to support external PI
    [controller.brd, controller.sch]
2021-06-25 Add slots to HDMI port
    [controller.brd, controller.sch]
2021-06-26 Organize Sikscreen
    [controller.brd, controller.sch]
2021-06-26 Length match differential paris
    [controller.brd, controller.sch]
2021-06-26 Beef up power 5V power line
    [controller.brd]
2021-06-26 Replace Arduino digitalRead with low level code
2021-06-26 Catch out ouf bound index via I2C
2021-06-26 Connect necessary CM4 pins, according to documentation
    [controller.brd, controller.sch]
2021-06-27 Ground HDMI chassis, add overvoltage protection
    [controller.brd, controller.sch]
2021-07-05 Changed to 4 layer stackup
    [controller.brd, controller.sch]
2021-07-06 Route differential pairs for HDMI
    [controller.brd, controller.sch]
2021-07-08 Completed 4 layer board
    [controller.brd]
2021-07-08 Final Board V3
    [controller.brd]
2021-07-08 Place cutout for antenna on all layers
    [controller.brd, controller.sch]
2021-07-09 Pull back internal layers around non plated drill holes
    [controller.brd, controller.sch]
2021-07-17 Fix HDMI pin offset
    [controller.brd]
2021-08-05 Edge Detection for Release button
2021-08-05 Added missing trace
    [controller.brd, controller.sch]
2021-08-06 Add level shifter for TX/RX
    [controller.brd, controller.sch]
2021-08-06 Change Buzzer trigger to interrupts
2021-08-07 Add input stage for Release button
    [controller.brd, controller.sch]
2021-08-07 Detect falling edege for release button
2021-08-09 Fix small pcb layout issues
    [controller.brd, controller.sch]
2021-08-09 Start renaming resistors for better organization
    [controller.brd, controller.sch]
2021-08-10 Relabel components
    [controller.brd, controller.sch]
2021-08-10 Adjust Panel Layout. Remove Pi, Additional Screws. Add Supply. Rearange Power Inlet and Release Button
    [BuzzerBoxPanel v23.f3d, BuzzerBoxPanel.f3d]
2021-08-17 Added combined header for buzzers
    [controller.brd, controller.sch]
2021-08-18 Add Dc-Dc Circuit, for possible 12V supply
    [controller.brd, controller.sch]
2021-08-19 Reduce connector pitch to 2mm for XLR-Board-Connection
    [controller.brd, controller.sch]
2021-08-19 Reduce connector pitch to 2mm for Release button
    [controller.brd, controller.sch]
2021-08-19 Move buzzer pcb connector away from GPIO Header
    [controller.brd]
2021-08-19 Add XLR-TOP-PCB
    [xlrpcb.brd, xlrpcb.sch]
2021-08-20 Added leds
    [controller.brd, controller.sch]
2021-08-20 Changed keepout etc for xlr connectors.
    [xlrpcb.brd, xlrpcb.sch]
2021-09-01 Change XLR PCB to equal spacing
    [xlrpcb.brd, xlrpcb.sch]
2021-09-01 Change Spacing on panel
    [BuzzerBoxPanel.f3d]
2021-09-05 Added ESD protection to USB
    [controller.brd, controller.sch]
2021-09-07 Enable WDT, Fix endless loop
    [BuzzerBox.cpp, rpi_communication.cpp]
2021-09-07 Handle incoming Serial resiliently against missing or added bytes
    [BuzzerBox.cpp, rpi_communication.cpp]
2021-09-09 Rearrange BuzzerIDs for new PCB-Layout
    [BuzzerBox.cpp]
2021-09-11 Added PE to XLR Board
    [controller.brd, xlrpcb.brd, xlrpcb.sch]
2021-09-24 V3 XLRBoard
    [xlrpcb.brd, xlrpcb.sch]
2021-10-16 Add DevKeys
    [devkeys.brd, devkeys.sch]
2021-11-04 Add TTL Adapter for Devkit
    [ttl_adapter.brd, ttl_adapter.sch]
2026-03-22 Attempt to fix selection change after locking bug
    [BuzzerBox.cpp]
2026-10-15 Fix buzzers locking up after bounces, stale re-locks on unlock and release button debounce
2026-10-17 Flash with an AVRISP mkII compatible programmer
    Switch avrdude from stk500v2 to avrispmkii for the Olimex AVR-ISP-MK2 and
    drop the baud rate, which a USB programmer doesn't use. Update the README
    to match.
2026-10-18 Add the firmware of the wireless buzzer (#31)
2026-10-24 Store the color of the buzzer's case (#33)

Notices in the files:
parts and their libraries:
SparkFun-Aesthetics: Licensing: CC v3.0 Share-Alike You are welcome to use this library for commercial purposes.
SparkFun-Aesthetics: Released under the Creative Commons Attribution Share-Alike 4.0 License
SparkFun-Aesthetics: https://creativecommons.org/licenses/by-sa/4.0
